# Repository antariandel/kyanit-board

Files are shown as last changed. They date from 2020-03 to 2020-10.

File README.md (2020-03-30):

# __Kyanit__ Board

## Introduction

Kyanit Board is part of the Kyanit ecosystem. See https://github.com/kyanit-project/kyanit for an
introduction to Kyanit.

Kyanit Board is the official Kyanit Core-compatible ESP8266-based controller board designed to be
used for home automation.

## The Kyanit Ecosystem

* [**Kyanit Core**](https://github.com/kyanit-project/kyanit)

The core Kyanit module, flashed into an ESP8266 board.

* [**Kyanit Board**](https://github.com/kyanit-project/kyanit-board)

This repo. A stylish, triangle-shaped ESP8266-based board built around an ESP-12F module, the
official Kyanit controller board.

* [**Kyanit CTL**](https://github.com/kyanit-project/kyanit-ctl)

Command-line utility for interacting with Kyanit.

* [**Kyanit API**](https://github.com/kyanit-project/kyanit-api)

Python API for interaction with Kyanit from Python code. (It is used by Kyanit CTL.)

## Board Files

The board is designed in KiCAD and is currently under development. First release to come soon...

## License Notice

Copyright (C) 2020 Zsolt Nagy

This program is free software: you can redistribute it and/or modify it under the terms of the
GNU General Public License as published by the Free Software Foundation, version 3 of the License.

This program is distributed in the hope that it will be useful, but WITHOUT ANY WARRANTY; without
even the implied warranty of MERCHANTABILITY or FITNESS FOR A PARTICULAR PURPOSE.
See the GNU General Public License for more details.
You should have received a copy of the GNU General Public License along with this program.
If not, see <https://www.gnu.org/licenses/>.

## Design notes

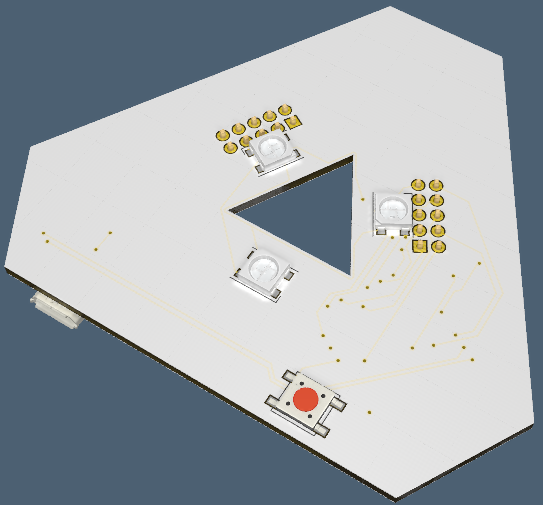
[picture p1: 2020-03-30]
preview_back.png

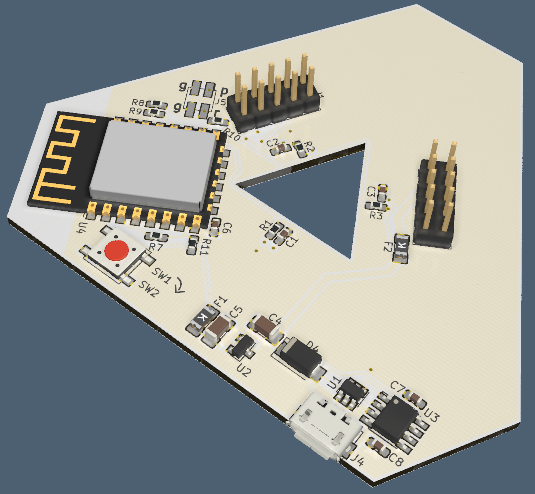
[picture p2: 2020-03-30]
preview_front.png

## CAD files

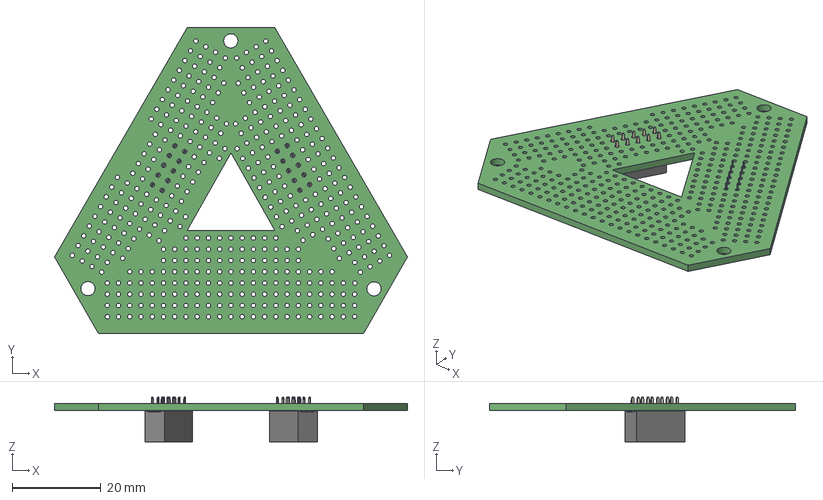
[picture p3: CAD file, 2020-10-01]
kicadprojects/addon_proto/kyanit-addon-proto.step
79.8 x 69.1 x 10.1 mm

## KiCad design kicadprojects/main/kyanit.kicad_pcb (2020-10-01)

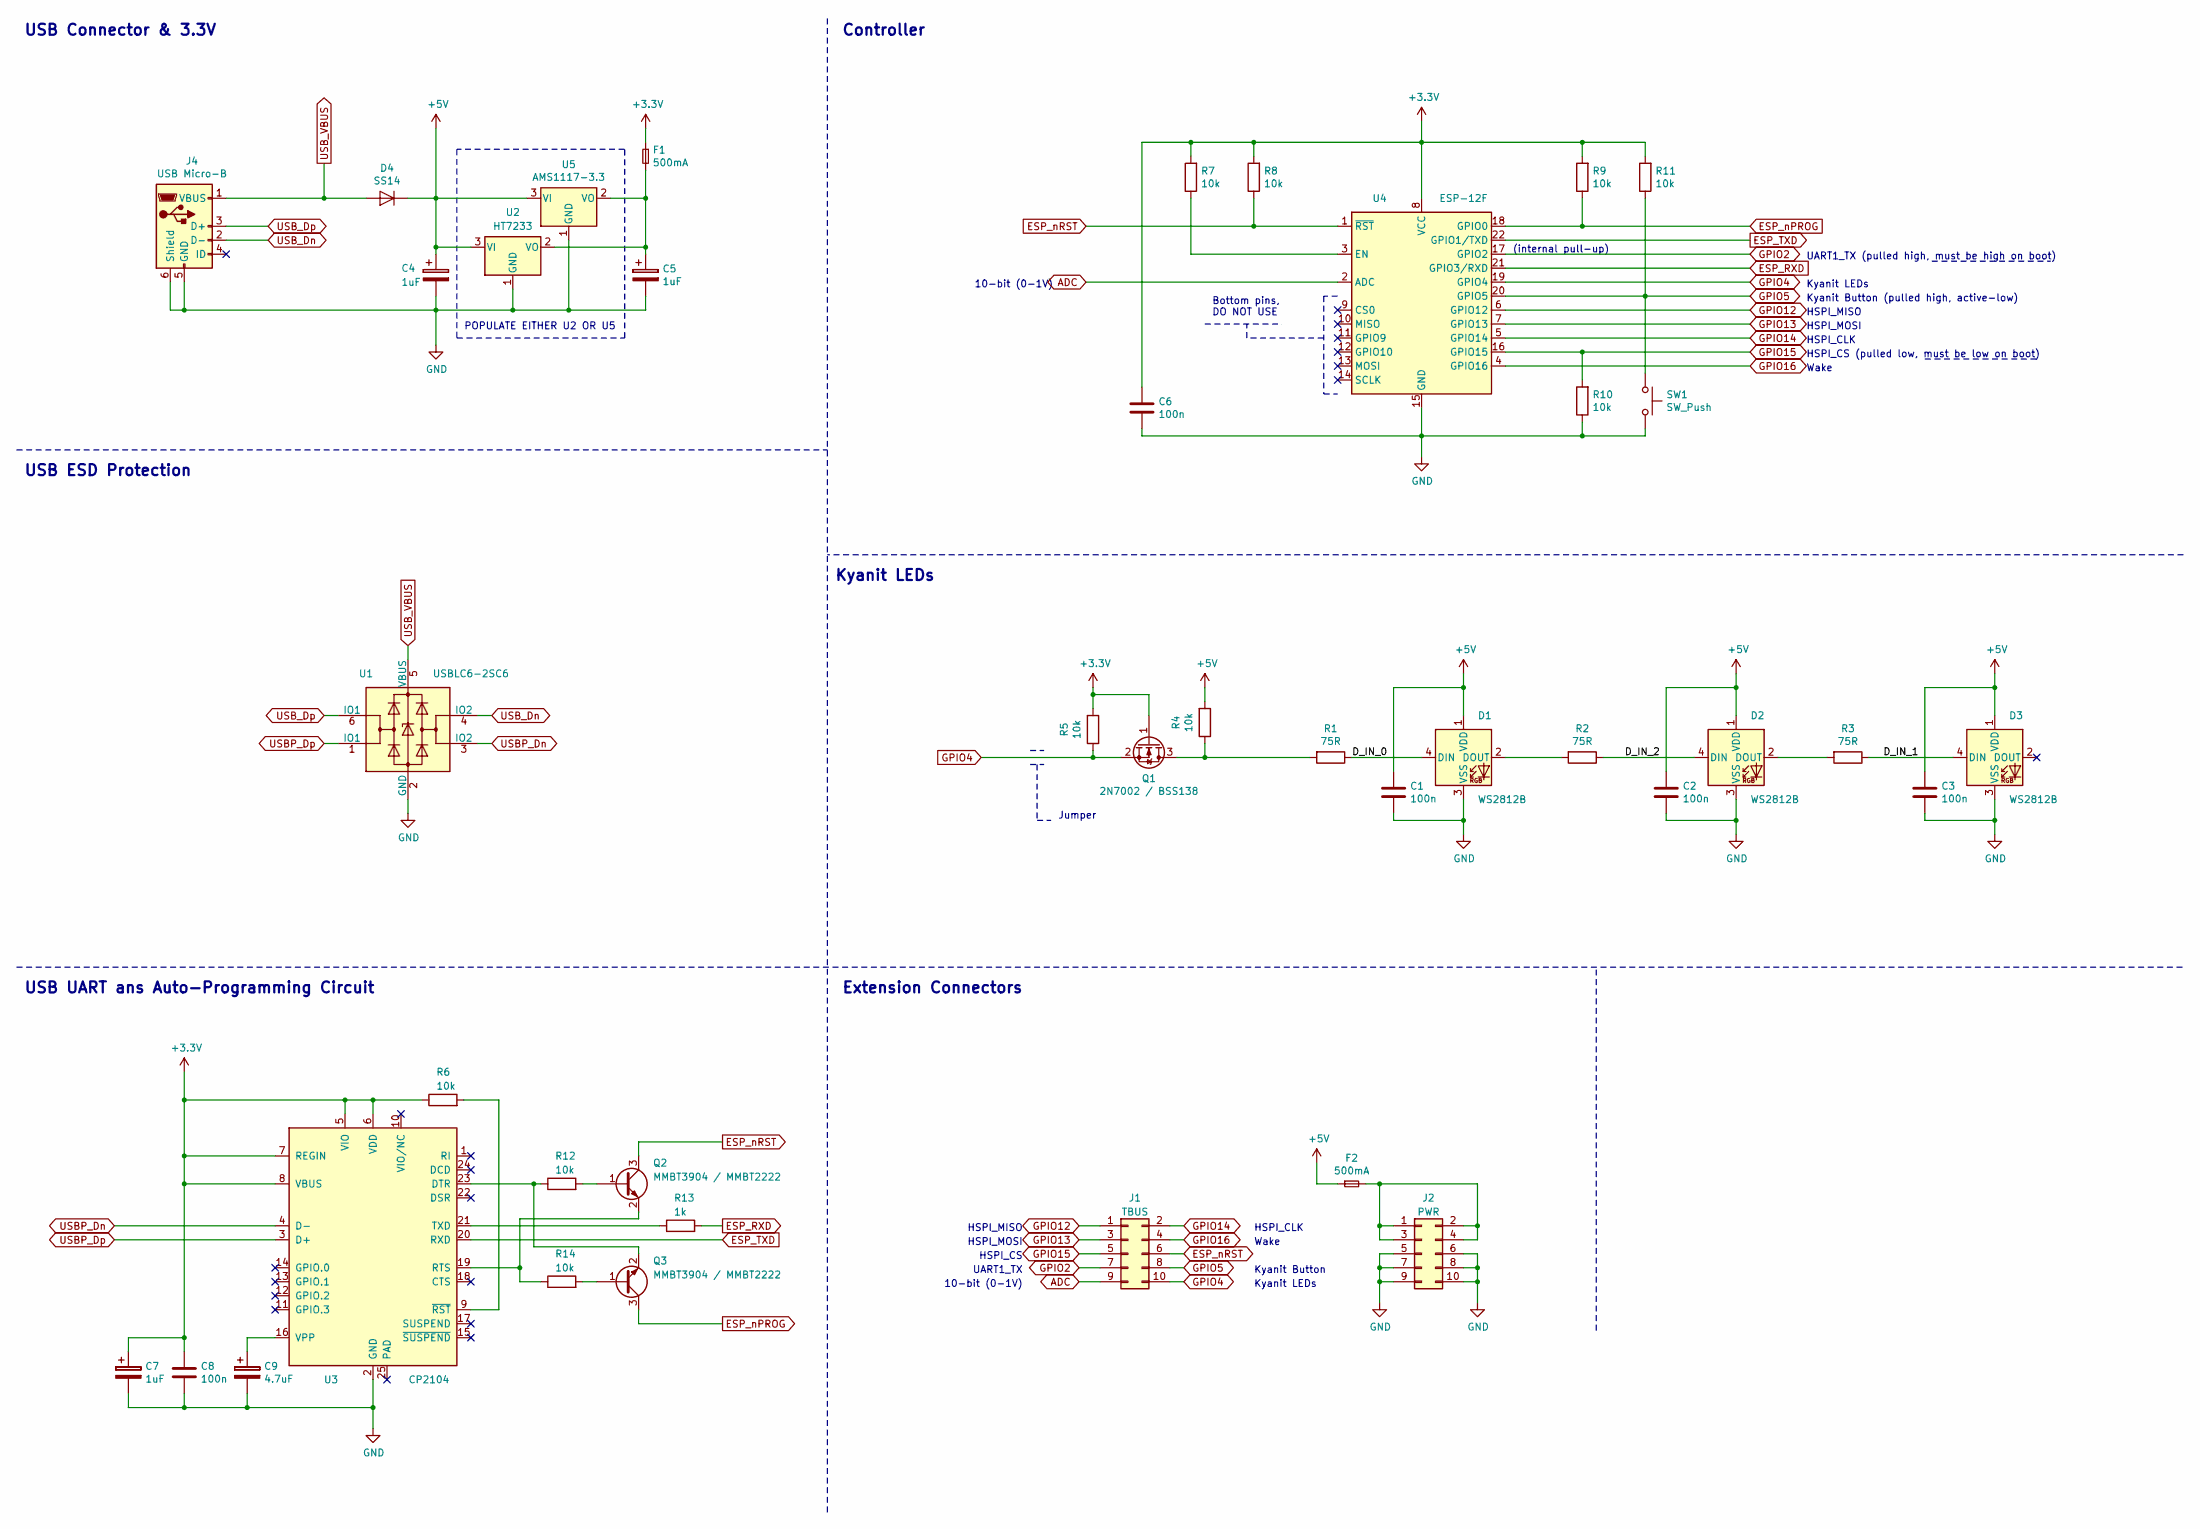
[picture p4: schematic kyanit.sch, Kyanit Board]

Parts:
C1, C2, C3, C6, C8: 100n; C_0603_1608Metric_Pad1.05x0.95mm_HandSolder
C4, C5, C7: 1uF; C_1206_3216Metric_Pad1.42x1.75mm_HandSolder
C9: 4.7uF; C_1206_3216Metric_Pad1.42x1.75mm_HandSolder
D1, D2, D3: WS2812B; LED_WS2812B_PLCC4_5.0x5.0mm_P3.2mm
D4: SS14; D_SMA
F1, F2: 500mA; Fuse_1206_3216Metric_Pad1.42x1.75mm_HandSolder
J1: TBUS; PinHeader_2x05_P2.54mm_Vertical
J2: PWR; PinHeader_2x05_P2.54mm_Vertical
J4: USB Micro-B; USB_Micro-B_Molex_47346-0001
Q1: 2N7002 / BSS138; SOT-23
Q2, Q3: MMBT3904 / MMBT2222; SOT-23
R1, R2, R3: 75R; R_0603_1608Metric_Pad1.05x0.95mm_HandSolder
R4, R5, R6, R7, R8, R9, R10, R11, R12, R14: 10k; R_0603_1608Metric_Pad1.05x0.95mm_HandSolder
R13: 1k; R_0603_1608Metric_Pad1.05x0.95mm_HandSolder
SW1: SW_Push; SW_SPST_EVPBF
U1: USBLC6-2SC6; SOT-23-6
U2: HT7233; SOT-23
U3: CP2104; QFN-24-1EP_4x4mm_P0.5mm_EP2.6x2.6mm
U4: ESP-12F; ESP-12E
U5: AMS1117-3.3; SOT-223-3_TabPin2

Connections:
+3V3: C6.1, C7.1, C8.1, F1.1, Q1.1 (G), R5.2, R6.1, R7.2, R8.2, R9.2, R11.2, U3.5 (VIO), U3.6 (VDD), U3.7 (REGIN), U3.8 (VBUS), U4.8 (VCC)
+5V: C1.1, C2.1, C3.1, C4.1, D1.1 (VDD), D2.1 (VDD), D3.1 (VDD), D4.1 (K), F2.1, R4.2, U2.3 (VI), U5.3 (VI)
/D_IN_0: D1.4 (DIN), R1.1
/D_IN_1: D3.4 (DIN), R3.1
/D_IN_2: D2.4 (DIN), R2.1
ADC: J1.9, U4.2 (ADC)
ESP_RXD: R13.2, U4.21 (GPIO3/RXD)
ESP_TXD: U3.20 (RXD), U4.22 (GPIO1/TXD)
ESP_nPROG: Q3.3 (C), R9.1, U4.18 (GPIO0)
ESP_nRST: J1.6, Q2.3 (C), R8.1, U4.1 (~RST)
GND: C1.2, C2.2, C3.2, C4.2, C5.2, C6.2, C7.2, C8.2, C9.2, D1.3 (VSS), D2.3 (VSS), D3.3 (VSS), J2.5, J2.6, J2.7, J2.8, J2.9, J2.10, J4.5 (GND), J4.6 (Shield), R10.1, SW1.2, U1.2 (GND), U2.1 (GND), U3.2 (GND), U4.15 (GND), U5.1 (GND)
GPIO2: J1.7, U4.17 (GPIO2)
GPIO4: J1.10, Q1.2 (S), R5.1, U4.19 (GPIO4)
GPIO5: J1.8, R11.1, SW1.1, U4.20 (GPIO5)
GPIO12: J1.1, U4.6 (GPIO12)
GPIO13: J1.3, U4.7 (GPIO13)
GPIO14: J1.2, U4.5 (GPIO14)
GPIO15: J1.5, R10.2, U4.16 (GPIO15)
GPIO16: J1.4, U4.4 (GPIO16)
unnamed: C5.1, F1.2, U2.2 (VO), U5.2 (VO)
unnamed: C9.1, U3.16 (VPP)
unnamed: D1.2 (DOUT), R2.2
unnamed: D2.2 (DOUT), R3.2
unnamed: F2.2, J2.1, J2.2, J2.3, J2.4
unnamed: Q1.3 (D), R1.2, R4.1
unnamed: Q2.1 (B), R12.2
unnamed: Q2.2 (E), R14.1, U3.19 (RTS)
unnamed: Q3.1 (B), R14.2
unnamed: Q3.2 (E), R12.1, U3.23 (DTR)
unnamed: R6.2, U3.9 (~RST)
unnamed: R7.1, U4.3 (EN)
unnamed: R13.1, U3.21 (TXD)
USBP_Dn: U1.3 (IO2), U3.4 (D-)
USBP_Dp: U1.1 (IO1), U3.3 (D+)
USB_Dn: J4.2 (D-), U1.4 (IO2)
USB_Dp: J4.3 (D+), U1.6 (IO1)
USB_VBUS: D4.2 (A), J4.1 (VBUS), U1.5 (VBUS)

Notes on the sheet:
USB Connector & 3.3V
USB ESD Protection
USB UART ans Auto-Programming Circuit
Extension Connectors
Kyanit LEDs
Controller
UART1_TX (pulled high, must be high on boot)
Kyanit Button (pulled high, active-low)
HSPI_MISO
HSPI_MOSI
HSPI_CLK
HSPI_CS (pulled low, must be low on boot)
10-bit (0-1V)
Bottom pins, DO NOT USE
(internal pull-up)
Wake
HSPI_CS
UART1_TX
Kyanit Button
Jumper
POPULATE EITHER U2 OR U5

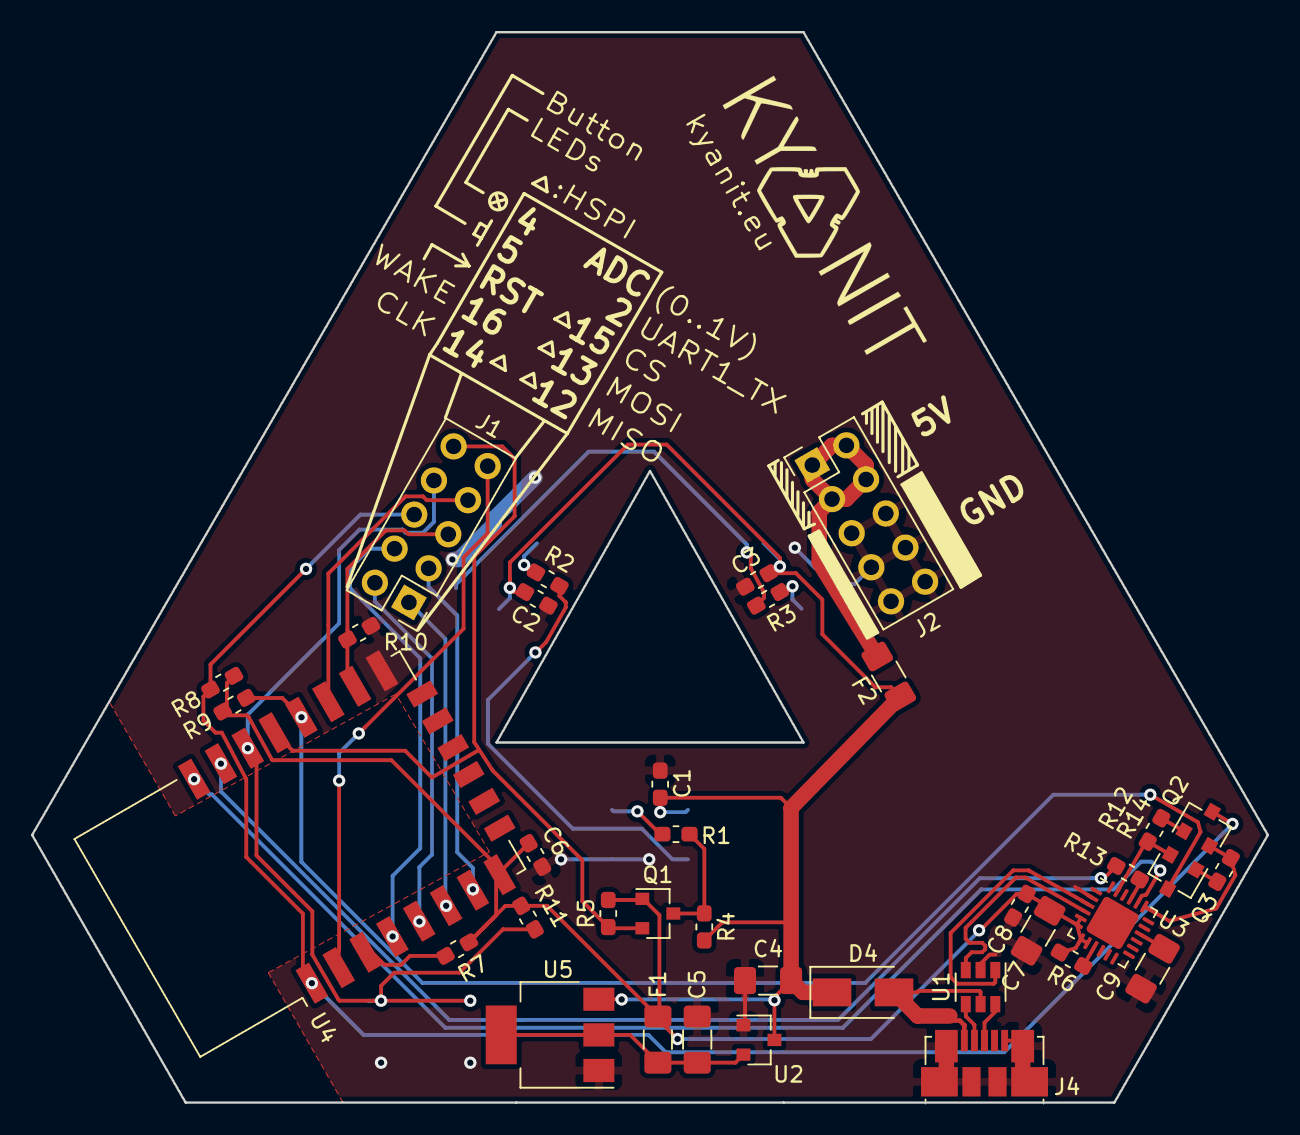
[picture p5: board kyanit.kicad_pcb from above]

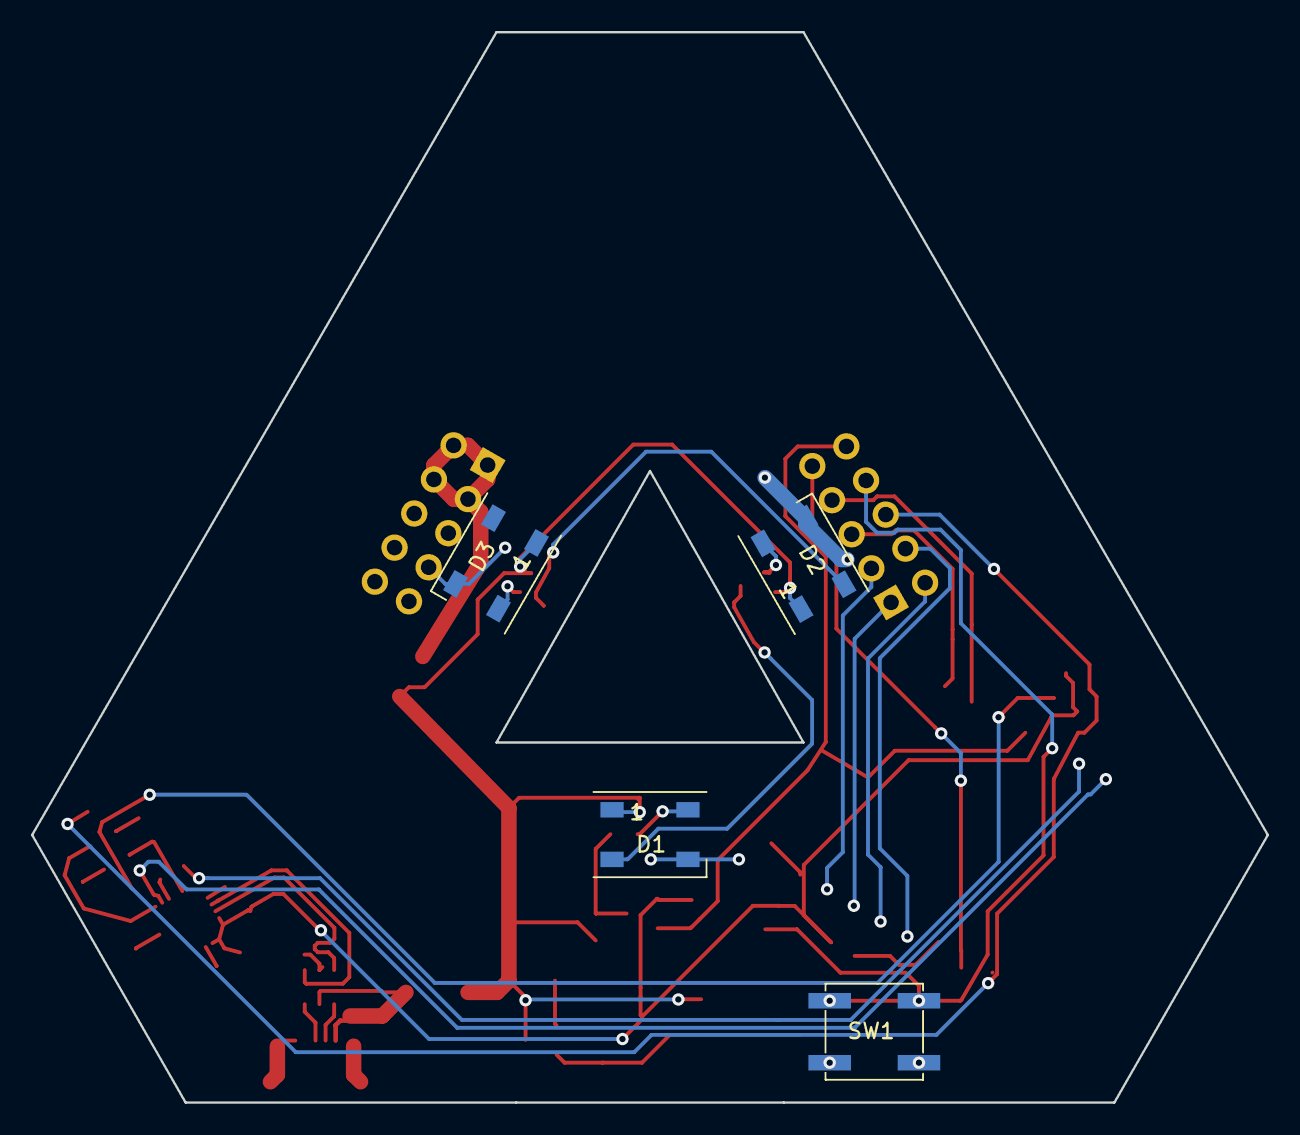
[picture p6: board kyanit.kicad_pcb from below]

Board: 2 copper layers, 79.8 x 69.1 mm, 41 parts (4 on the bottom side), 37 nets.

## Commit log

2020-03-30 initial: add Kyanit Board files
    [kyanit.kicad_pcb, kyanit.sch]
2020-03-30 fix: fix 3dshapes and generate previews
    [kyanit.kicad_pcb]
2020-04-05 feat: rename gpio nets, add pinout to silkscreen
    [kyanit.kicad_pcb, kyanit.sch]
2020-04-05 fix: update layout (should have been commited with 3b8f99cb)
    [kyanit.kicad_pcb]
2020-10-01 feat!: add auto-program and proto board
    [kyanit-addon-proto.kicad_pcb, kyanit-addon-proto.sch, kyanit-addon-proto.step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]
